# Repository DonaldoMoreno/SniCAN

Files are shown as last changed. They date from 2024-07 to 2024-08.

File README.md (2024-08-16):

# SniCAN 

## Descripción

Este proyecto consiste en el desarrollo de un sistema embebido que incluye tanto hardware como software. El objetivo del proyecto es crear un dispositivo autónomo capaz de adquirir los mensaje de un bus de CAN utilizando un microcontrolador IMXRT1060IEC, 
y una interfaz gráfica para la configuración y monitoreo.

## Características

- **Microcontrolador:** IMXRT1060IEC
- **Sensores y periféricos:** [Lista de sensores y periféricos, por ejemplo, MPU6050, OLED Display]
- **Software:**
  - **Firmware:** Implementado en C/C++ con uso de yocto zephyr.
  - **Interfaz gráfica:** Implementada en QT con Python.
- **Interfaz de usuario:** Interfaz gráfica (GUI) y línea de comandos (CLI) para configuración y monitoreo.
- **Conectividad:** CAN bus.
  
## Estructura del Repositorio

```plaintext
/SniCAN
├── /docs
├── /hardware
│   ├── /schematics
│   ├── /bom
│   ├── /fabricacion
│   ├── /simulaciones
│   ├── /documentacion
│   └── /mecanico
├── /firmware*
├── /software*
├── /simulaciones*
└── /tools*

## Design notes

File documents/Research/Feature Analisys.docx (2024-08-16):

Pins

Kicad files to make a custom Teensy 4.1, based on the official Teensy schematics, but exposing all pins for testing. All the 55 pins except D41 are brought out for testing

Pins need for:

- 1 SPI *
- 4 PWM *
- 3 CAN *
- 10 GPIO *
- 1 Power *
- LED Pin *
- Serial *
- I2C *
- Ethernet/ Future implementation
- Micro SD/ Future implementation
- LCD/ Future implementation

Displays

ILI9341 320x240 Color TFT

These displays are the best supported on Teensy 4.1, with multiple high-performance libraries for fast updates speed. ILI9341 is usually the best display to use, due to superior software support.

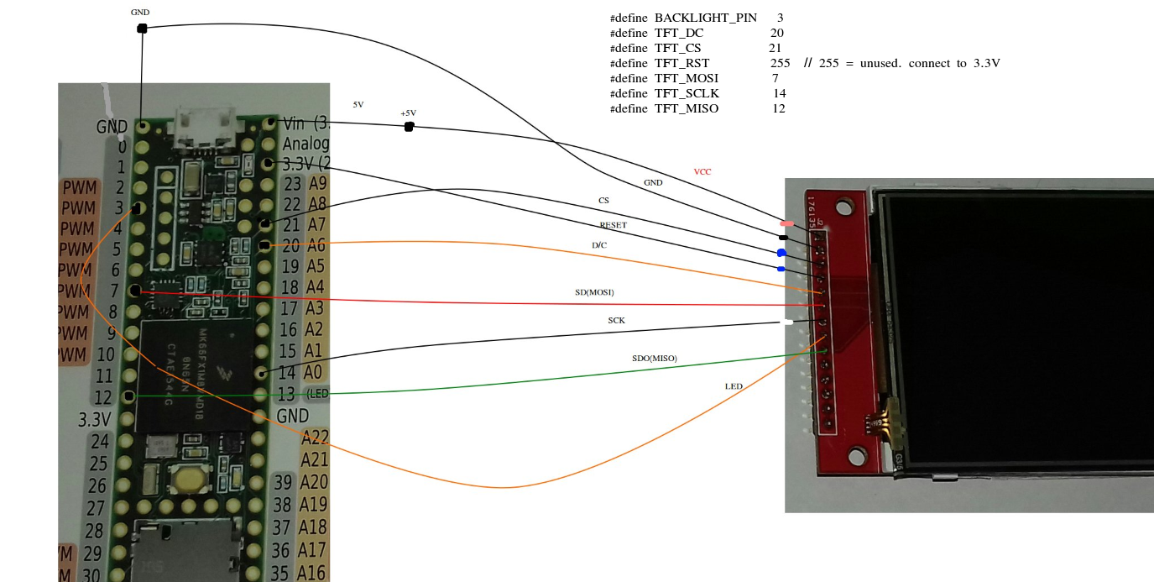
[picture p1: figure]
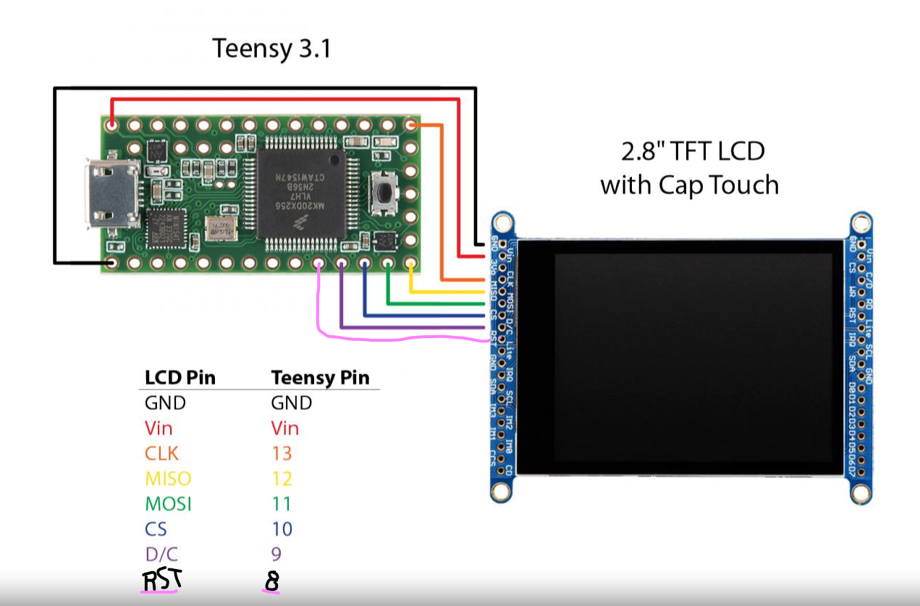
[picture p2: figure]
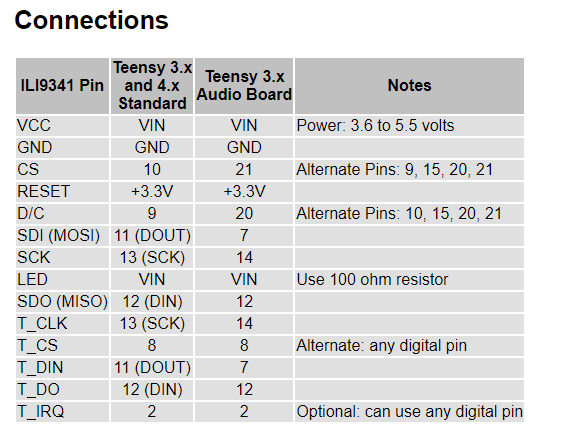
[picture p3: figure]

PWM Timers

32 timers’ control PWM pins or may be used for other timing functions. Normally these timers are accessed with analog Write or libraries, but they have many very advanced features which may be accessed by direct hardware register use.

- ~~FlexPWM1 Module0~~ ~~- Controls PWM pins 1, 44, 45.~~
- ~~FlexPWM1 Module1~~ ~~- Controls PWM pins 0, 42, 43.~~ (Usados por CAN)
- FlexPWM1 Module2 - Controls PWM pins 24, ~~46, 47~~.
- FlexPWM1 Module3 - Controls PWM pins 7, 8, 25.
- FlexPWM2 Module0 - Controls PWM pins 4, 33.
- FlexPWM2 Module1 - Controls PWM pin 5.
- FlexPWM2 Module2 - Controls PWM pins 6, 9.
- FlexPWM2 Module3 - Controls PWM pins 36, 37.
- FlexPWM3 Module0 - Controls PWM pin 53.
- FlexPWM3 Module1 - Controls PWM pins 28, 29.
- FlexPWM3 Module2 - No pins accessible.
- FlexPWM3 Module3 - Controls PWM pin 41.
- FlexPWM4 Module0 - Controls PWM pin 22.
- FlexPWM4 Module1 - Controls PWM pin 23.
- FlexPWM4 Module2 - Controls PWM pins 2, 3.

Special Timers

These extra timers allow delays, analog sample rate timing, carrier modulation, and other special timing tasks to be performed, without consuming any of the normal PWM-oriented timers.

- GPT1 - Generic 32-bit timer

CAN

3 ports for CAN bus allow connecting to automotive & industrial control systems which use CAN communication. A CAN transceiver chip must be added to complete the electrical interface between Teensy 4.1 and the CAN bus. ([CAN1 pin 22 and 23], [CAN2 pin 0 and 1], [CAN FD pin 30 and 31])

Digital Input Pins

Digital pins may be used to receive signals. Teensy 4.1 pins default to INPUT most with a "keeper" resistor. Teensy 4.1 pins accept 0 to 3.3V signals. The pins are not 5V tolerant. Do not drive any digital pin higher than 3.3V.

Power

USB Power

Normally Teensy is powered by your PC or USB hub, through a USB cable. The USB power arrives at the VUSB pin, which is connected to VIN and powers the entire board.

VIN Pin

When USB power is not used, 5V power may be applied to the VIN pin. Because VIN & VUSB are connected, power should not be applied to VIN while a USB cable is used, to prevent the possibility of power flowing back into your computer. Alternately, a pair of pads on the bottom side may be cut apart, to separate VUSB from VIN, allowing power to be safely applied while USB is in use. (TODO: VUSB-VIN pads photo, right side)

3.3V Power

Teensy 4.1 has a voltage regulator which reduces the 5V VUSB / VIN power to 3.3V for use by the main processor and most other parts. Additional circuitry may be powered from the 3.3V pin. The recommended maximum for external 3.3V usage is 250mA. Teensy 4.1 is not meant to receive power on its 3.3V pin, but this can be done with special modification.

LED Pin

Pin 13 has an orange LED connected. The LED can be very convenient to show status info. When pin 13 is used as an input, the external signal must be able to drive the LED when logic HIGH. pin Mode INPUT_PULLUP should not be used with pin 13.

Serial

8 serial ports allow you to connect serial devices, such as MIDI, GPS receivers, DMX lighting, ESP wireless modules, etc. All 8 serial ports are fully independent and can transfer data simultaneously. None are shared with USB (as is done on some Arduino boards). All 8 ports include FIFOs for better performance at high-speed baud rates. [SERIAL TX 20 and RX 21]

I2C

3 ports for I2C (signals SDA & SCL) allow connecting a wide variety of chips which use I2C communication. The Wire library is used for I2C. Each I2C chip connected to the same SDA/SCL wires needs a unique address. Multiple I2C ports allow you to easily use more than 1 chip with the same address. All I2C ports support 100, 400, and 1000 kbit/sec speeds.

SPI

3 ports for SPI (signals MOSI, MISO, SCK) allow connecting higher speed chips, SD cards, and displays which use SPI communication. The SPI library provides software support for SPI. The first SPI port features a FIFO for higher sustained speed transfers. Each SPI chip requires a chip select (CS) signal. Most libraries using SPI can use any digital pin. The SPI ports provide special hardware-controlled CS pins, which are used by specially optimized libraries for higher performance. ([SPI1 MOSI 26, SCK 27, CS 38, MISO 39],)

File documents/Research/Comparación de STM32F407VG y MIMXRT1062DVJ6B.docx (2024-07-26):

Comparación de Microcontroladores: STM32F4 vs. MIMXRT1062DVJ6B para Aplicaciones de Alto Rendimiento y Comunicación CAN

Microcontrolador | STM32F407VG | MIMXRT1062DVJ6B
Fabricante | STMicroelectronics | NXP
Arquitectura | ARM Cortex-M4 | ARM Cortex-M7
Frecuencia de reloj | 168 MHz | 600 MHz
Memoria Flash | 1 MB | Externa (FlexSPI)
SRAM | 192 KB | 1 MB en chip
Interfaces de comunicación | - 3x CAN - 4x USART - 3x SPI - 3x I2C - 2x USB OTG (FS y HS) | - 1x CAN FD - 1x CAN 2.0 - 8x UART - 4x SPI - 4x I2C - 2x USB OTG (FS y HS)
Aceleradores DSP y FPU | Si | Si
DMA | 12 canales | 32 canales
GPIO | 140 pines | 150 pines
ADC | 3x ADC de 12 bits | 2x ADC de 12 bits
DAC | 2x DAC de 12 bits | 1x DAC de 12 bits
Temperatura de operación | -40°C a 85°C | -40°C a 105°C
Paquetes | LQFP, BGA | LQFP, BGA
Disponibilidad | Buena en el mercado. | Buena en el mercado.
Precio (+100 piezas) | $11.36 | $12.73
Certificaciones | Varias, incluidas aplicaciones automotrices. | Varias, incluidas aplicaciones automotrices.
Seguridad | Características básicas de seguridad. | Características avanzadas de seguridad.

Comparación

1. Arquitectura y Rendimiento:

- STM32F4: Basado en ARM Cortex-M4, hasta 168 MHz.

- MIMXRT1062DVJ6B: Basado en ARM Cortex-M7, hasta 600 MHz. El Cortex-M7 ofrece un mayor rendimiento en comparación con el Cortex-M4, especialmente para aplicaciones que requieren procesamiento intensivo.

2. Memoria:

- STM32F4: Hasta 1 MB de Flash interna y 192 KB de SRAM.

- MIMXRT1062DVJ6B: No tiene Flash interna, usa memoria externa (FlexSPI), pero tiene 1 MB de SRAM en chip.

3. Interfaces de Comunicación:

- STM32F4: 3x CAN, más interfaces USART, SPI, I2C, y USB.

- MIMXRT1062DVJ6B: 1x CAN FD, 1x CAN 2.0, más interfaces UART, SPI, I2C, y USB. La inclusión de CAN FD es una ventaja para aplicaciones que requieren velocidades de datos más altas en la comunicación CAN.

4. DMA:

- STM32F4: 12 canales.

- MIMXRT1062DVJ6B: 32 canales, lo que permite una mayor flexibilidad y capacidad para manejar múltiples periféricos simultáneamente.

5. Temperatura de Operación:

- Ambos microcontroladores operan en un rango industrial, pero el MIMXRT1062DVJ6B soporta hasta 105°C, lo cual es una ventaja para aplicaciones en entornos más exigentes.

6. GPIO:

- STM32F4: Hasta 140 pines.

- MIMXRT1062DVJ6B: Hasta 150 pines, proporcionando más opciones de conexión.

Conclusión Características

- STM32F4 es una excelente opción para aplicaciones que requieren una combinación equilibrada de rendimiento y funcionalidades con una arquitectura Cortex-M4 probada.

- MIMXRT1062DVJ6B es más adecuado para aplicaciones que requieren un alto rendimiento y capacidad de procesamiento, gracias a su núcleo Cortex-M7 y su alta frecuencia de reloj. Además, la inclusión de CAN FD lo hace ideal para aplicaciones automotrices avanzadas y otras aplicaciones que requieren comunicación de alta velocidad en el bus CAN.

COMPARATIVA DE COSTOS DE DESARROLLO PARA EL STM32F4 Y EL MIMXRT1062DVJ6B

Una comparación de costos considerando una implementación básica para CAN, incluyendo el costo del microcontrolador y los componentes esenciales para la comunicación CAN.

### STM32F407VG

7. Costo del Microcontrolador:
  - $9.27 (1000) a $14.64 USD por unidad.
8. Transceptor CAN:
  - MCP2551 o similar: Aproximadamente $0.50 a $1.50 USD por unidad.
9. Componentes Pasivos (resistencias, condensadores, etc.):
  - Aproximadamente $0.50 a $1.00 USD por unidad.
10. Conectores y Placa de Circuito Impreso (PCB):
  - Aproximadamente $2 a $5 USD por unidad.

### Costo Total Estimado para STM32F4:

- Total: $13 a $22 USD por unidad.

### MIMXRT1062DVJ6B

1. Costo del Microcontrolador:
  - $10.01 (1000) a $15.90 USD por unidad.
2. Transceptor CAN FD:
  - MCP2562FD o similar: Aproximadamente $1 a $2 USD por unidad.
3. Componentes Pasivos (resistencias, condensadores, etc.):
  - Aproximadamente $0.50 a $1.00 USD por unidad.
4. Conectores y Placa de Circuito Impreso (PCB):
  - Aproximadamente $2 a $5 USD por unidad.

### Costo Total Estimado para MIMXRT1062DVJ6B:

- Total: $10.50 a $18 USD por unidad.

### Comparación de Costos

Componente | STM32F4 (STM32F407VG) | MIMXRT1062DVJ6B
Microcontrolador | $9.27 - $14.64 USD | $10.01 - $15.90 USD
Transceptor CAN | $0.50 - $1.50 USD | $1 - $2 USD
Componentes Pasivos | $0.50 - $1 USD | $0.50 - $1 USD
Conectores y PCB | $2 - $5 USD | $2 - $5 USD
Costo Total Estimado | $12.27 - $22.14 USD | $13.51 - $23.90 USD

Fuente

- Digikey (https://www.digikey.com/en/products/detail/nxp-usa-inc/MIMXRT1062DVJ6B/13574426?gad_source=1)
- Mouser (https://www.mouser.com/c/semiconductors/embedded-processors-controllers/microcontrollers-mcu/arm-microcontrollers-mcu/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)

Conclusión costos

El MIMXRT1062DVJ6B ofrece un costo ligeramente superior para una implementación básica de CAN en comparación con el STM32F4. Sin embargo, el MIMXRT1062DVJ6B proporciona un rendimiento superior y soporte para CAN FD, lo que puede ser beneficioso por los requisitos específicos de aplicación.

COMPARATIVA DE ECOSISTEMAS DE DESARROLLO PARA EL STM32F4 Y EL MIMXRT1062DVJ6B

### Ecosistema de Desarrollo STM32F407VG

1. Herramientas de Desarrollo
  - STM32CubeIDE: IDE basado en Eclipse, proporciona un entorno de desarrollo integrado con soporte completo para depuración y compilación.
  - STM32CubeMX: Herramienta para la configuración de microcontroladores STM32 y generación de código de inicialización.
  - KEIL MDK: IDE de desarrollo profesional con compilador ARM y herramientas avanzadas de depuración.
  - IAR Embedded Workbench: IDE con compilador y depurador optimizado para aplicaciones embebidas.
2. Bibliotecas y Middleware
  - STM32Cube HAL (Hardware Abstraction Layer): Biblioteca de abstracción de hardware que facilita el uso de periféricos.
  - STM32 Standard Peripheral Libraries: Librerías de bajo nivel para acceso a periféricos.
  - CMSIS (Cortex Microcontroller Software Interface Standard): Conjunto de APIs estándar para programación en microcontroladores Cortex.
3. Kits de Desarrollo y Placas
  - STM32 Nucleo Boards: Placas de desarrollo versátiles y económicas con soporte para Arduino shields.
  - Discovery Kits: Placas con funcionalidades avanzadas, incluyendo pantallas, sensores y conectividad.
  - Evaluation Boards: Placas completas con todos los periféricos y interfaces expuestas para pruebas exhaustivas.
4. Documentación y Recursos
  - Manuales de Referencia y Datasheets: Documentos detallados sobre el funcionamiento interno y características del microcontrolador.
  - Guías de Usuario y Aplicación: Documentos que explican cómo utilizar y configurar los diferentes periféricos y características.
  - Ejemplos de Código: Proyectos de ejemplo para una variedad de aplicaciones y periféricos.
5. Soporte de Comunidad
  - ST Community: Foro oficial de STMicroelectronics con soporte de expertos y usuarios.
  - STM32 Forums: Foros independientes donde los desarrolladores comparten experiencias y soluciones.
  - GitHub: Repositorios con proyectos de código abierto y ejemplos.
6. Capacitación y Cursos
  - MOOCs y Webinars: Cursos online y webinars ofrecidos por ST y otros proveedores de formación.
  - Documentación Educativa: Recursos educativos y libros sobre programación y desarrollo con STM32.

### Ecosistema de Desarrollo MIMXRT1062DVJ6B

1. Herramientas de Desarrollo
  - MCUXpresso IDE: Entorno de desarrollo integrado proporcionado por NXP, basado en Eclipse, con soporte completo para depuración y compilación.
  - MCUXpresso Config Tools: Herramienta para la configuración de microcontroladores y generación de código de inicialización.
  - IAR Embedded Workbench: IDE con compilador y depurador optimizado para aplicaciones embebidas.
  - KEIL MDK: IDE de desarrollo profesional con compilador ARM y herramientas avanzadas de depuración.
2. Bibliotecas y Middleware
  - MCUXpresso SDK: Conjunto de software development kits que incluyen drivers, middleware y ejemplos de aplicaciones.
  - FreeRTOS: Soporte integrado para el sistema operativo en tiempo real FreeRTOS.
  - USB y TCP/IP Stacks: Pilas de comunicación USB y TCP/IP para desarrollo de aplicaciones de conectividad.
3. Kits de Desarrollo y Placas
  - MIMXRT1060-EVK: Kit de evaluación completo para el MIMXRT1062, con todos los periféricos y interfaces necesarias para pruebas exhaustivas.
  - Development Boards de Terceros: Placas de desarrollo ofrecidas por otros fabricantes compatibles con el microcontrolador.
4. Documentación y Recursos
  - Manuales de Referencia y Datasheets: Documentos detallados sobre el funcionamiento interno y características del microcontrolador.
  - Guías de Usuario y Aplicación: Documentos que explican cómo utilizar y configurar los diferentes periféricos y características.
  - Ejemplos de Código: Proyectos de ejemplo para una variedad de aplicaciones y periféricos.
5. Soporte de Comunidad
  - NXP Community: Foro oficial de NXP con soporte de expertos y usuarios.
  - GitHub: Repositorios con proyectos de código abierto y ejemplos.
  - Stack Overflow: Comunidad activa con preguntas y respuestas relacionadas con el desarrollo en microcontroladores NXP.
6. Capacitación y Cursos
  - Webinars y Seminarios: Eventos educativos y seminarios en línea ofrecidos por NXP.
  - Documentación Educativa: Recursos educativos y libros sobre programación y desarrollo con microcontroladores NXP.

### Comparación de Ecosistemas

Aspecto | STM32F407VG | MIMXRT1062DVJ6B
IDE Principal | STM32CubeIDE, KEIL, IAR | MCUXpresso IDE, KEIL, IAR
Herramientas de Configuración | STM32CubeMX | MCUXpresso Config Tools
SDK y Middleware | STM32Cube HAL, CMSIS | MCUXpresso SDK, FreeRTOS, USB/TCP/IP
Placas de Desarrollo | Nucleo Boards, Discovery Kits | MIMXRT1060-EVK, placas de terceros
Documentación | Completa y detallada | Completa y detallada
Comunidad | Amplia, activa, múltiples foros | Amplia, activa, NXP Community, GitHub
Capacitación | MOOCs, webinars, documentación educativa | Webinars, seminarios, documentación educativa
Ejemplos de Código | Abundantes y variados | Abundantes y variados

### Conclusión comparación de ecosistemas de desarrollo

Ambos ecosistemas de desarrollo son robustos y completos, ofreciendo una amplia gama de herramientas, bibliotecas, documentación y soporte comunitario. La elección entre el ecosistema STM32F4 y el MIMXRT1062DVJ6B dependerá de las preferencias personales del desarrollador, la experiencia previa y las necesidades específicas del proyecto. El ecosistema STM32 es muy conocido por su facilidad de uso y la abundancia de recursos educativos, mientras que el ecosistema NXP ofrece herramientas poderosas y soporte para características avanzadas como CAN FD y alto rendimiento de procesamiento.

COMPARATIVA DE CERTIFICACIONES DE DESARROLLO PARA EL STM32F4 Y EL MIMXRT1062DVJ6B

### Certificaciones y Conformidades del MIMXRT1062DVJ6B

1. Certificación Automotriz
  - AEC-Q100: El MIMXRT1062DVJ6B no está calificado bajo AEC-Q100, que es un estándar para la fiabilidad de componentes electrónicos en aplicaciones automotrices. Sin embargo, NXP tiene otros microcontroladores en su línea que sí cumplen con esta certificación.
2. Certificación de Seguridad Funcional
  - IEC 61508: NXP proporciona productos que pueden ser utilizados en aplicaciones que requieren el cumplimiento con IEC 61508 para la seguridad funcional. Aunque el MIMXRT1062DVJ6B no está específicamente certificado, puede ser parte de un sistema que cumple con esta norma.
  - ISO 26262: Similar a IEC 61508, este microcontrolador puede ser utilizado en aplicaciones que necesitan cumplir con ISO 26262 para la seguridad funcional automotriz, pero no está específicamente certificado para ello.
3. Certificación Industrial
  - IEC 60730: NXP ofrece soporte para IEC 60730, que es una norma relevante para aplicaciones seguras en electrodomésticos. El MIMXRT1062DVJ6B puede ser utilizado en sistemas que necesitan cumplir con esta norma.
4. Certificación Médica
  - IEC 62304: Aunque no está específicamente certificado, el MIMXRT1062DVJ6B puede ser parte de dispositivos médicos que necesitan cumplir con la norma IEC 62304 para el software de dispositivos médicos.

### Certificaciones y Conformidades del STM32F407VG

1. Certificación Automotriz
  - AEC-Q100: Algunos modelos de la serie STM32F4, incluidos ciertos modelos específicos, están calificados bajo AEC-Q100. Sin embargo, el STM32F407VG en particular no está certificado AEC-Q100. STMicroelectronics ofrece otros modelos dentro de la serie STM32 que sí cumplen con esta certificación.
2. Certificación de Seguridad Funcional
  - IEC 61508: La serie STM32F4 puede ser utilizada en aplicaciones que requieren cumplimiento con IEC 61508 para la seguridad funcional. Sin embargo, el STM32F407VG no está específicamente certificado para esta norma, aunque puede ser parte de un sistema que cumple con IEC 61508.
  - ISO 26262: Similar a IEC 61508, algunos microcontroladores de la serie STM32 están diseñados para ayudar a cumplir con la norma ISO 26262, pero el STM32F407VG en particular no tiene esta certificación explícita.
3. Certificación Industrial
  - IEC 60730: La serie STM32F4, incluido el STM32F407VG, puede ser utilizada en aplicaciones que necesitan cumplir con la norma IEC 60730 para la seguridad de electrodomésticos y aplicaciones industriales.
4. Certificación Médica
  - IEC 62304: Los microcontroladores de la serie STM32, incluidos ciertos modelos de la serie F4, pueden ser utilizados en dispositivos médicos que necesitan cumplir con IEC 62304 para el software de dispositivos médicos. El STM32F407VG puede ser parte de un sistema que cumple con esta norma, pero no está específicamente certificado.

### Comparación de Certificaciones

Certificación | MIMXRT1062DVJ6B | STM32F407VG
Automotriz (AEC-Q100) | No | No (otros modelos STM32F4 sí)
Seguridad Funcional (IEC 61508) | No específicamente, pero puede utilizarse en sistemas que cumplen | No específicamente, pero puede utilizarse en sistemas que cumplen
Seguridad Funcional (ISO 26262) | No específicamente, pero puede utilizarse en sistemas que cumplen | No específicamente, pero puede utilizarse en sistemas que cumplen
Industrial (IEC 60730) | Puede ser utilizado en sistemas que cumplen | Puede ser utilizado en sistemas que cumplen
Médica (IEC 62304) | Puede ser utilizado en sistemas que cumplen | Puede ser utilizado en sistemas que cumplen

### Conclusión comparativa de certificaciones

Ninguno de los microcontroladores (MIMXRT1062DVJ6B y STM32F407VG) está específicamente certificado para todas las normas mencionadas, pero ambos pueden ser utilizados en sistemas que cumplen con estas certificaciones, dependiendo de la implementación y las evaluaciones adicionales realizadas por los desarrolladores. La elección entre estos microcontroladores dependerá en gran medida de otros factores como el rendimiento, los periféricos y el soporte del ecosistema, además de las certificaciones específicas requeridas para la aplicación final.

COMPARATIVA DE SEGURIDAD DE DESARROLLO PARA EL STM32F4 Y EL MIMXRT1062DVJ6B

### Características de Seguridad del MIMXRT1062DVJ6B

1. Arranque Seguro (Secure Boot)
  - Características: Soporte para arranque seguro que asegura que solo código firmado y autorizado puede ejecutarse en el dispositivo.
  - Beneficio: Protege contra la ejecución de firmware no autorizado o malicioso.
2. Almacenamiento Seguro
  - Flash Seguro: Soporte para particiones seguras en memoria flash.
  - Protección de Lectura y Escritura: Configuración para proteger ciertas áreas de memoria de ser leídas o escritas por código no autorizado.
3. Criptografía
  - Aceleradores Criptográficos: Hardware integrado para acelerar operaciones criptográficas como AES, RSA, SHA, y ECC.
  - Generador de Números Aleatorios (TRNG): Hardware que proporciona números aleatorios de alta calidad para operaciones criptográficas.
4. Gestión de Claves
  - Almacenamiento Seguro de Claves: Módulos específicos para almacenar claves criptográficas de manera segura.
  - Generación y Gestión de Claves: Soporte para la generación, almacenamiento y gestión segura de claves.
5. Detección de Intrusiones
  - Monitores de Voltaje y Temperatura: Detecta condiciones fuera de los parámetros normales que podrían indicar un intento de intrusión.
  - Protección contra Manipulaciones: Mecanismos para detectar y responder a intentos de manipulación física del dispositivo.
6. Protección de Memoria
  - Unidad de Protección de Memoria (MPU): Configura y protege regiones de memoria contra accesos no autorizados.
  - Códigos de Integridad: Verificación de la integridad del código y datos almacenados en memoria.

### Características de Seguridad del STM32F407VG

1. Arranque Seguro (Secure Boot)
  - Características: No tiene soporte nativo para arranque seguro. Sin embargo, puede ser implementado mediante software adicional y configuraciones específicas.
2. Almacenamiento Seguro
  - Protección de Lectura y Escritura: Ofrece opciones para proteger la memoria flash contra lecturas y escrituras no autorizadas mediante niveles de protección (RDP - Read Protection).
3. Criptografía
  - Aceleradores Criptográficos: Incluye aceleradores de hardware para operaciones AES y hash (SHA-1, SHA-256).
  - Generador de Números Aleatorios (RNG): Hardware para generar números aleatorios, aunque es un RNG no certificado como TRNG.
4. Gestión de Claves
  - Almacenamiento Seguro de Claves: No tiene módulos específicos para el almacenamiento seguro de claves, pero las claves pueden ser protegidas mediante software.
  - Generación y Gestión de Claves: Las claves deben ser gestionadas y almacenadas a través de software y configuraciones adicionales.
5. Detección de Intrusiones
  - Monitores de Voltaje y Temperatura: No tiene monitores específicos para detección de intrusiones.
  - Protección contra Manipulaciones: Carece de mecanismos avanzados para detectar manipulación física.
6. Protección de Memoria
  - Unidad de Protección de Memoria (MPU): Soporta configuración de MPU para proteger regiones de memoria contra accesos no autorizados.
  - Códigos de Integridad: Puede implementar verificaciones de integridad de código mediante software.

### Comparación de Seguridad

Característica | MIMXRT1062DVJ6B | STM32F407VG
Arranque Seguro (Secure Boot) | Sí | No nativo, puede ser implementado vía software
Almacenamiento Seguro | Flash seguro, protección de lectura/escritura | Protección de lectura/escritura mediante RDP
Criptografía | Aceleradores para AES, RSA, SHA, ECC; TRNG | Aceleradores para AES, SHA; RNG no certificado
Gestión de Claves | Almacenamiento y gestión segura de claves | No tiene módulos específicos, depende de software
Detección de Intrusiones | Monitores de voltaje y temperatura, protección contra manipulación | No tiene detección avanzada de intrusiones
Protección de Memoria | MPU, códigos de integridad | MPU, puede implementar verificaciones de integridad vía software

### Conclusión seguridad

El MIMXRT1062DVJ6B de NXP ofrece un conjunto más robusto de características de seguridad en comparación con el STM32F407VG de STMicroelectronics. Incluye soporte nativo para arranque seguro, aceleradores criptográficos avanzados, almacenamiento seguro de claves y detección de intrusiones, lo que lo hace más adecuado para aplicaciones que requieren altos niveles de seguridad.

Por otro lado, el STM32F407VG ofrece algunas características básicas de seguridad como protección de memoria y aceleradores criptográficos, pero carece de soporte nativo para arranque seguro y almacenamiento seguro de claves, lo que puede requerir soluciones adicionales basadas en software para cumplir con requisitos de seguridad más estrictos.

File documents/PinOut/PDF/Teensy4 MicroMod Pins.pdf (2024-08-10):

Pin | MM Pin | Name | GPIO | Serial | I2C | SPI | PWM | CAN | Audio | XBAR | FlexIO | Analog | SD/CSI/LCD
0 | 19 | AD_B0_03 | 1.3 | Serial1(6) RX | SPI1(3) CS0 | PWM1_X1 2_RX | IO-17
1 | 17 | AD_B0_02 | 1.2 | Serial1(6) TX | SPI1(3) MISO | PWM1_X0 2_TX | IO-16
2 | 47 | EMC_04 | 4.4 | PWM4_A2 | 2:TX_DATAIO-06 | 1:4
3 | 32 | EMC_05 | 4.5 | PWM4_B2 | 2:TX_SYNCIO-07 | 1:5
4 | 10 | EMC_06 | 4.6 | PWM2_A0 | 2:TX_BCLKIO-08 | 1:6
5 | 18 | EMC_08 | 4.8 | PWM2_A1 | 2:RX_DATAIO-17 | 1:8
6 | 71 | B0_10 | 2.10 | PWM2_A2, QT4_1 | 1:TX3_RX1 | 2:10 | LCD_DATA6
7 | 56 | B1_01 | 2.17 | Serial4(4) RX | PWM1_B3 | 1:TX_DATAIO-15 | 2:17, 3:17
8 | 54 | B1_00 | 2.16 | Serial4(4) TX | PWM1_A3 | 1:RX_DATAIO-14 | 2:16, 3:16
9 | 69 | B0_11 | 2.11 | PWM2_B2,QT4_2 | 1:TX2_RX2 | 2:11 | LCD_DATA7
10 | 55 | B0_00 | 2.0 | SPI(4) CS0 | QT1_0 | MQS_RIGHT | 2:0 | LCD_CLK
11 | 59 | B0_02 | 2.2 | | | SPI(4) MOSI | QT1_2 | 1_TX | | | 2:2 | | LCD_HSYNC
12 | 61 | B0_01 | 2.1 | SPI(4) MISO | QT1_1 | MQS_LEFT | 2:1 | LCD_ENABLE
13 | 57 | B0_03 | 2.3 | | | SPI(4) SCK | QT2_0 | 1_RX | | | 2:3 | | LCD_VSYNC
14/A0 | 34 | AD_B1_02 | 1.18 | Serial3(2) TX | QT3_2 | SPDIF_OUT | 3:2 | A1:7, A2:7
15/A1 | 38 | AD_B1_03 | 1.19 | Serial3(2) RX | | | QT3_3 | | SPDIF_IN | | 3:3 | A1:8, A2:8
16/A2 | 20 | AD_B1_07 | 1.23 | Serial2(3) RX Wire2(3) SCL | SPDIF_EXTCLK | 3:7 | A1:12, A2:12 | USDHC2_DATA3
17/A3 | 22 | AD_B1_06 | 1.22 | Serial2(3) TX Wire2(3) SDA | SPDIF_LOCK | 3:6 | A1:11, A2:11 | USDHC2_DATA2
18/A4 | 12 | AD_B1_01 | 1.17 | Serial3(2) RTS Wire(1) SDA | QT3_1 | 3:1 | A1:6, A2:6
19/A5 | 14 | AD_B1_00 | 1.16 | Serial3(2) CTS Wire(1) SCL | QT3_0 | 3:0 | A1:5, A2:5
20/A6 | 52 | AD_B1_10 | 1.26 | Serial5(8) TX | 1:RX_SYNC | 3:10 | A1:15, A2:15
21/A7 | 50 | AD_B1_11 | 1.27 | Serial5(8) RX | 1:RX_BCLK | 3:11 | A1:0, A2:0
22/A8 | 49 | AD_B1_08 | 1.24 | PWM4_A0 1_TX | 3:8 | A1:13, A2:13 | USDHC2_CMD
23/A9 | 58 | AD_B1_09 | 1.25 | PWM4_A1 1_RX | 1:MCLK | 3:9 | A1:14, A2:14 | USDHC2_CLK
24/A10 | 53 | AD_B0_12 | 1.12 | Serial6(1) TX Wire1(4) SCL | PWM1_X2 | A1:1
25/A11 | 51 | AD_B0_13 | 1.13 | Serial6(1) RX Wire1(4) SDA | PWM1_X3 GPT1_CLK | A1:2
26/A12 | 67 | AD_B1_14 | 1.30 | SPI1(3) MOSI | 1:TX_BCLK | 3:14 | A2:3
27/A13 | 8 | AD_B1_15 | 1.31 | SPI1(3) SCK | 1:TX_SYNC | 3:15 | A2:4
28 | 4 | EMC_32 | 3.18 | Serial7(7) RX | | | PWM3_B1
29 | 16 | EMC_31 | 4.31 | Serial7(7) TX | | SPI2(1) CS1 | PWM3_A1
30 | 41 | EMC_37 | 3.23 | GPT1_3 | 3_RX | 3:MCLK IO-23
31 | 43 | EMC_36 | 3.22 | GPT1_2 | 3_TX | 3:TX_DATAIO-22
32 | 65 | B0_12 | 2.12 | 1:TX1_RX3IO-10 | 2:12 | LCD_DATA8
33 | 63 | EMC_07 | 4.7 | PWM2_B0 | 2:MCLK IO-09 | 1:7
SD Pins - Cable connector(T4 34-39)
34 | 66 | SD_B0_03 | 3.15 | Serial5(8) RTS | | SPI2(1) MISO | PWM1_B1 | | | IO-07 | | | DATA1
35 | 64 | SD_B0_02 | 3.14 | Serial5(8) CTS | | SPI2(1) MOSI | PWM1_A1 | | | IO-06 | | | DATA0
36 | 60 | SD_B0_01 | 3.13 | | Wire2(3) SDA | SPI2(1) CS0 | PWM1_B0 | | | IO-05 | | | CLK
37 | 62 | SD_B0_00 | 3.12 | | Wire2(3) SCL | SPI2(1) SCK | PWM1_A0 | | | IO-04 | | | CMD
38 | 68 | SD_B0_04 | 3.16 | Serial5(8) TX | FLEXSPI B_SSO_B PWM1_A2 | IO-08 | DATA2
39 | 70 | SD_B0_05 | 3.17 | Serial5(8) RX | | FLEXSPI B_DQS | PWM1_B2 | | | IO-09 | | | DATA3
Micromod new pins
40 | 40 | B0_04 | 2:04 | | Wire3(2) SCL | | QT2_1 | | | | 2:4 | | LCD_DATA0
41 | 42 | B0_05 | 2:05 | | Wire3(2) SDA | | QT2_2 | | | | 2:5 | | LCD_DATA1
42 | 44 | B0_06 | 2:06 | | | | QT3_0 | | | | 2:6 | | LCD_DATA2
43 | 46 | B0_07 | 2:07 | | | | QT3_1 | | | | 2:7 | | LCD_DATA3
44 | 48 | B0_08 | 2:08 | | | | QT3_2 | | | | 2:8 | | LCD_DATA4
45 | 73 | B0_09 | 2:09 | | | | QT4_0 | | | | 2:9 | | LCD_DATA5
USB Pins
HUSB D+ 35
HUSB D- 37
USB D+ | 3
USB D- | 5

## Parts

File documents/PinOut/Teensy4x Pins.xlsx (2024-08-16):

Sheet: T4
Pin | Name | GPIO | Serial | I2C | SPI | PWM | CAN | Audio | XBAR | FlexIO | Analog | SD
0 | AD_B0_03 | 1.3 | Serial1(6) RX |  | SPI1(3) CS0 | PWM1_X1 | 2_RX |  | IO-17
1 | AD_B0_02 | 1.2 | Serial1(6) TX |  | SPI1(3) MISO | PWM1_X0 | 2_TX |  | IO-16
2 | EMC_04 | 4.4 |  |  |  | PWM4_A2 |  | 2:TX_DATA | IO-06 | 1:4
3 | EMC_05 | 4.5 |  |  |  | PWM4_B2 |  | 2:TX_SYNC | IO-07 | 1:5
4 | EMC_06 | 4.6 |  |  |  | PWM2_A0 |  | 2:TX_BCLK | IO-08 | 1:6
5 | EMC_08 | 4.8 |  |  |  | PWM2_A1 |  | 2:RX_DATA | IO-17 | 1:8
6 | B0_10 | 2.10 |  |  |  | PWM2_A2, QT4_1 |  | 1:TX3_RX1 |  | 2:10
7 | B1_01 | 2.17 | Serial2(4) RX |  |  | PWM1_B3 |  | 1:TX_DATA | IO-15 | 2:17, 3:17
8 | B1_00 | 2.16 | Serial2(4) TX |  |  | PWM1_A3 |  | 1:RX_DATA | IO-14 | 2:16, 3:16
9 | B0_11 | 2.11 |  |  |  | PWM2_B2, QT4_2 |  | 1:TX2_RX2 |  | 2:11
10 | B0_00 | 2.0 |  |  | SPI(4) CS0 | QT1_0 |  | MQS_RIGHT |  | 2:0
11 | B0_02 | 2.2 |  |  | SPI(4) MOSI | QT1_2 | 1_TX |  |  | 2:2
12 | B0_01 | 2.1 |  |  | SPI(4) MISO | QT1_1 |  | MQS_LEFT |  | 2:1
13 | B0_03 | 2.3 |  |  | SPI(4) SCK | QT2_0 | 1_RX |  |  | 2:3
14/A0 | AD_B1_02 | 1.18 | Serial3(2) TX |  |  | QT3_2 |  | SPDIF_OUT |  | 3:2 | A1:7, A2:7
15/A1 | AD_B1_03 | 1.19 | Serial3(2) RX |  |  | QT3_3 |  | SPDIF_IN |  | 3:3 | A1:8, A2:8
16/A2 | AD_B1_07 | 1.23 | Serial4(3) RX | Wire1(3) SCL |  |  |  | SPDIF_EXTCLK |  | 3:7 | A1:12, A2:12
17/A3 | AD_B1_06 | 1.22 | Serial4(3) TX | Wire1(3) SDA |  |  |  | SPDIF_LOCK |  | 3:6 | A1:11, A2:11
18/A4 | AD_B1_01 | 1.17 | Serial3(2) RTS | Wire(1) SDA |  | QT3_1 |  |  |  | 3:1 | A1:6, A2:6
19/A5 | AD_B1_00 | 1.16 | Serial3(2) CTS | Wire(1) SCL |  | QT3_0 |  |  |  | 3:0 | A1:5, A2:5
20/A6 | AD_B1_10 | 1.26 | Serial5(8) TX |  |  |  |  | 1:RX_SYNC |  | 3:10 | A1:15, A2:15
21/A7 | AD_B1_11 | 1.27 | Serial5(8) RX |  |  |  |  | 1:RX_BCLK |  | 3:11 | A1:0, A2:0
22/A8 | AD_B1_08 | 1.24 |  |  |  | PWM4_A0 | 1_TX |  |  | 3:8 | A1:13, A2:13
23/A9 | AD_B1_09 | 1.25 |  |  |  | PWM4_A1 | 1_RX | 1:MCLK |  | 3:9 | A1:14, A2:14
--- | ---- | ---- | ------ | --- | --- | --- | --- | ---- | ---- | ----- | ------
24/A10 | AD_B0_12 | 1.12 | Serial6(1) TX | Wire2(4) SCL |  | PWM1_X2 |  |  |  |  | A1:1
25/A11 | AD_B0_13 | 1.13 | Serial6(1) RX | Wire2(4) SDA |  | PWM1_X3 | GPT1_CLK |  |  |  | A1:2
26/A12 | AD_B1_14 | 1.30 |  |  | SPI1(3) MOSI |  |  | 1:TX_BCLK |  | 3:14 | A2:3
27/A13 | AD_B1_15 | 1.31 |  |  | SPI1(3) SCK |  |  | 1:TX_SYNC |  | 3:15 | A2:4
28 | EMC_32 | 3.18 | Serial7(7) RX |  |  | PWM3_B1
29 | EMC_31 | 4.31 | Serial7(7) TX |  | SPI2(1) CS1 | PWM3_A1
30 | EMC_37 | 3.23 |  |  |  | GPT1_3 | 3_RX | 3:MCLK | IO-23
31 | EMC_36 | 3.22 |  |  |  | GPT1_2 | 3_TX | 3:TX_DATA | IO-22
32 | B0_12 | 2.12 |  |  |  |  |  | 1:TX1_RX3 | IO-10 | 2:12
33 | EMC_07 | 4.7 |  |  |  | PWM2_B0 |  | 2:MCLK | IO-09 | 1:7
34 | SD_B0_03 | 3.15 | Serial5(8) RTS |  | SPI2(1) MISO | PWM1_B1 |  |  | IO-07 |  |  | DATA1
35 | SD_B0_02 | 3.14 | Serial5(8) CTS |  | SPI2(1) MOSI | PWM1_A1 |  |  | IO-06 |  |  | DATA0
36 | SD_B0_01 | 3.13 |  | Wire1(3) SDA | SPI2(1) CS0 | PWM1_B0 |  |  | IO-05 |  |  | CLK
37 | SD_B0_00 | 3.12 |  | Wire1(3) SCL | SPI2(1) SCK | PWM1_A0 |  |  | IO-04 |  |  | CMD
38 | SD_B0_05 | 3.17 | Serial5(8) RX |  | SPI2(1) B_DQS | PWM1_B2 |  |  | IO-09 |  |  | DATA3
39 | SD_B0_04 | 3.16 | Serial5(8) TX |  | SPI2(1) B_SSO_B | PWM1_A2 |  |  | IO-08 |  |  | DATA2

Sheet: T4 - GPIO
Pin | Name | GPIO | Serial | I2C | SPI | PWM | CAN | Audio | XBAR | FlexIO | Analog | SD
1 | AD_B0_02 | 1.02 | Serial1(6) TX |  | SPI1(3) MISO | PWM1_X0 | 2_TX |  | IO-16
0 | AD_B0_03 | 1.03 | Serial1(6) RX |  | SPI1(3) CS0 | PWM1_X1 | 2_RX |  | IO-17
24/A10 | AD_B0_12 | 1.12 | Serial6(1) TX | Wire2(4) SCL |  | PWM1_X2 |  |  |  |  | A1:1
25/A11 | AD_B0_13 | 1.13 | Serial6(1) RX | Wire2(4) SDA |  | PWM1_X3 | GPT1_CLK |  |  |  | A1:2
19/A5 | AD_B1_00 | 1.16 | Serial3(2) CTS | Wire(1) SCL |  | QT3_0 |  |  |  | 3:0 | A1:5, A2:5
18/A4 | AD_B1_01 | 1.17 | Serial3(2) RTS | Wire(1) SDA |  | QT3_1 |  |  |  | 3:1 | A1:6, A2:6
14/A0 | AD_B1_02 | 1.18 | Serial3(2) TX |  |  | QT3_2 |  | SPDIF_OUT |  | 3:2 | A1:7, A2:7
15/A1 | AD_B1_03 | 1.19 | Serial3(2) RX |  |  | QT3_3 |  | SPDIF_IN |  | 3:3 | A1:8, A2:8
17/A3 | AD_B1_06 | 1.22 | Serial4(3) TX | Wire1(3) SDA |  |  |  | SPDIF_LOCK |  | 3:6 | A1:11, A2:11
16/A2 | AD_B1_07 | 1.23 | Serial4(3) RX | Wire1(3) SCL |  |  |  | SPDIF_EXTCLK |  | 3:7 | A1:12, A2:12
22/A8 | AD_B1_08 | 1.24 |  |  |  | PWM4_A0 | 1_TX |  |  | 3:8 | A1:13, A2:13
23/A9 | AD_B1_09 | 1.25 |  |  |  | PWM4_A1 | 1_RX | 1:MCLK |  | 3:9 | A1:14, A2:14
20/A6 | AD_B1_10 | 1.26 | Serial5(8) TX |  |  |  |  | 1:RX_SYNC |  | 3:10 | A1:15, A2:15
21/A7 | AD_B1_11 | 1.27 | Serial5(8) RX |  |  |  |  | 1:RX_BCLK |  | 3:11 | A1:0, A2:0
26/A12 | AD_B1_14 | 1.30 |  |  | SPI1(3) MOSI |  |  | 1:TX_BCLK |  | 3:14 | A2:3
27/A13 | AD_B1_15 | 1.31 |  |  | SPI1(3) SCK |  |  | 1:TX_SYNC |  | 3:15 | A2:4
10 | B0_00 | 2.00 |  |  | SPI(4) CS0 | QT1_0 |  | MQS_RIGHT |  | 2:0
12 | B0_01 | 2.01 |  |  | SPI(4) MISO | QT1_1 |  | MQS_LEFT |  | 2:1
11 | B0_02 | 2.02 |  |  | SPI(4) MOSI | QT1_2 | 1_TX |  |  | 2:2
13 | B0_03 | 2.03 |  |  | SPI(4) SCK | QT2_0 | 1_RX |  |  | 2:3
6 | B0_10 | 2.10 |  |  |  | PWM2_A2, QT4_1 |  | 1:TX3_RX1 |  | 2:10
9 | B0_11 | 2.11 |  |  |  | PWM2_B2, QT4_2 |  | 1:TX2_RX2 |  | 2:11
32 | B0_12 | 2.12 |  |  |  |  |  | 1:TX1_RX3 | IO-10 | 2:12
8 | B1_00 | 2.16 | Serial2(4) TX |  |  | PWM1_A3 |  | 1:RX_DATA | IO-14 | 2:16, 3:16
7 | B1_01 | 2.17 | Serial2(4) RX |  |  | PWM1_B3 |  | 1:TX_DATA | IO-15 | 2:17, 3:17
37 | SD_B0_00 | 3.12 |  | Wire1(3) SCL | SPI2(1) SCK | PWM1_A0 |  |  | IO-04 |  |  | CMD
36 | SD_B0_01 | 3.13 |  | Wire1(3) SDA | SPI2(1) CS0 | PWM1_B0 |  |  | IO-05 |  |  | CLK
35 | SD_B0_02 | 3.14 | Serial5(8) CTS |  | SPI2(1) MOSI | PWM1_A1 |  |  | IO-06 |  |  | DATA0
34 | SD_B0_03 | 3.15 | Serial5(8) RTS |  | SPI2(1) MISO | PWM1_B1 |  |  | IO-07 |  |  | DATA1
39 | SD_B0_04 | 3.16 | Serial5(8) TX |  | SPI2(1) B_SSO_B | PWM1_A2 |  |  | IO-08 |  |  | DATA2
38 | SD_B0_05 | 3.17 | Serial5(8) RX |  | SPI2(1) B_DQS | PWM1_B2 |  |  | IO-09 |  |  | DATA3
28 | EMC_32 | 3.18 | Serial7(7) RX |  |  | PWM3_B1
31 | EMC_36 | 3.22 |  |  |  | GPT1_2 | 3_TX | 3:TX_DATA | IO-22
30 | EMC_37 | 3.23 |  |  |  | GPT1_3 | 3_RX | 3:MCLK | IO-23
2 | EMC_04 | 4.04 |  |  |  | PWM4_A2 |  | 2:TX_DATA | IO-06 | 1:4
3 | EMC_05 | 4.05 |  |  |  | PWM4_B2 |  | 2:TX_SYNC | IO-07 | 1:5
4 | EMC_06 | 4.06 |  |  |  | PWM2_A0 |  | 2:TX_BCLK | IO-08 | 1:6
33 | EMC_07 | 4.07 |  |  |  | PWM2_B0 |  | 2:MCLK | IO-09 | 1:7
5 | EMC_08 | 4.08 |  |  |  | PWM2_A1 |  | 2:RX_DATA | IO-17 | 1:8
29 | EMC_31 | 4.31 | Serial7(7) TX |  | SPI2(1) CS1 | PWM3_A1

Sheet: T4 card like
Audio | Prop | Native | GPIO | Audio | FlexIO | Xbar | I2C | CAN | SPI | Serial | Analog | PWM | Digital |  |  | Digital | PWM | Analog | Serial | SPI | CAN | I2C | Xbar | FlexIO | Audio | GPIO | Native | Prop | Audio
G | GND |  |  |  |  |  |  |  |  |  | GND |  |  |  |  | Vin |  |  |  |  |  |  |  |  |  |  |  | 5V
 |  | AD_B0_03 | 1.3 |  |  | 17 |  | RX2 | CS1 | RX1 |  | 1X1 | 0 |  |  | GND |  |  |  |  |  |  |  |  |  |  |  | G | G
 |  | AD_B0_02 | 1.2 |  |  | 16 |  | TX2 | MISO1 | TX1 |  | 1X0 | 1 |  |  | 3.3V 250mA max |  |  |  |  |  |  |  |  |  |  |  | 3V | 3.3
 | S | EMC_04 | 4.4 | O2 | 1:4 | 6 |  |  |  |  |  | 4A2 | 2 |  |  | 23 | 4A1 | A9 |  |  | RX1 |  |  | 3:9 | MCL1 | 1.25 | AD-B1_09 |  | A
M |  | EMC_05 | 4.5 | LR2 | 1:5 | 7 |  |  |  |  |  | 4B2 | 3 |  |  | 22 | 4A0 | A8 |  |  | TX1 |  |  | 3:08:00 |  | 1.24 | AD_B1_08
A |  | EMC_06 | 4.6 | BCL2 | 1:6 | 8 |  |  |  |  |  | 2A0 | 4 |  |  | 21 |  | A7 | RX5 |  |  |  |  | 3:11:00 | BCL1 | 1.27 | AD_B1_11 |  | A
A | A-EN | EMC_08 | 4.8 | IN2 | 1:8 | 17 |  |  |  |  |  | 2A1 | 5 |  |  | 20 |  | A6 | TX5 |  |  |  |  | 3:10:00 | LRC1 | 1.26 | AD_B1_10 |  | A
 | M-CS | B0_10 | 2.10 | O1D | 2:10 |  |  |  |  |  |  | 2A2, Q41 | 6 |  |  | 19 | Q30 | A5 | CTS3 |  |  | SCL0 |  | 3:00:00 |  | 1.16 | AD_B1_00 | S | C
 | L-EN | B1_01 | 2.17 | O1A | 2:17, 3:17 | 15 |  |  |  | RX2 |  | 1B3 | 7 |  |  | 18 | Q31 | A4 |  |  |  | SDA0 |  | 3:01:00 |  | 1.17 | AD_B1_01 | S | C
 |  | B1_00 | 2.16 | IN1 | 2:16, 3:16 | 14 | sda0 |  |  | TX2 |  | 1A3 | 8 |  |  | 17 |  | A3 | TX4 |  |  | SDA1 |  | 3:06:00 |  | 1.22 | AD_B1_06
 |  | B0_11 | 2.11 | O1C | 2:11 |  |  |  |  |  |  | 2B2,Q42 | 9 |  |  | 16 |  | A2 | RX4 |  |  | SCL1 |  | 3:07:00 |  | 1.23 | AD_B1_07
S |  | B0_00 | 2.0 | MQR | 2:0 |  |  |  | CS0 |  |  | Q10 | 10 |  |  | 15 | Q33 | A1 | RX3 |  |  |  |  | 3:03:00 | SPDI | 1.19 | AD_B1_03 |  | V
SM | M/L | B0_02 | 2.2 |  | 2:2 |  |  | TX1 | MOSI0 |  |  | Q12 | 11 |  |  | 14 | Q32 | A0 | TX3 |  |  |  |  | 3:02:00 | SPDO | 1.18 | AD_B1_02
SM | M | B0_01 | 2.1 | MQL | 2:1 |  |  |  | MISO0 |  |  | Q11 | 12 |  |  | 13 | Q20 | LED |  | SCK0 | rx1 |  |  | 2:03:00 |  | 2.3 | B0_03 | M | SM
 |  |  |  |  |  |  |  |  |  | Bottom SMT Pins
 |  | AD_B0_12 | 1.12 |  |  |  | SCL2 |  |  | TX6 | A10-1 | 1X2 | 24 |  |  | 25 | 1X3 | A11-1 | RX6 |  |  | SDA2 |  |  |  | 1.13 | AD_B0_13
 |  | AD_B1_14 | 1.30 |  | 3:14 |  |  |  | MOSI1 |  | A12-2 |  | 26 |  |  | 27 |  | A13-2 |  | SCK1 |  |  |  | 3:15 |  | 1.31 | AD_B1_15
 |  | EMC_32 | 3.18 |  |  |  |  |  |  | RX7 |  | 3B1 | 28 |  |  | 29 | 3A1 |  | TX7 |  |  |  |  |  |  | 4.31 | EMC_31
 |  | EMC_37 | 3.23 |  |  | 23 |  | RX3 |  |  |  | G13 | 30 |  |  | 31 | G12 |  |  |  | TX3 |  | 22 |  |  | 3.22 | EMC_36
 |  | B0_12 | 2.12 | O1B | 2:12:00 | 10 |  |  |  |  |  |  | 32 |  |  | 33 | 2B0 |  |  |  | TX1 |  | 9 | 1:7 | MCL2 | 4.7 | EMC_07
 |  |  |  |  |  |  |  |  |  | Bottom SDIO Pins
 |  | SD_B0_03 | 3.15 |  | DATA1 | 7 |  |  | MISO2 |  |  | 1B1 | 34 | ______| | |_____
 |  | SD_B0_02 | 3.14 |  | DATA0 | 6 |  |  | MOSI2 | CTS5 |  | 1A1 | 35 | _______| | |_______
 |  |  |  |  |  |  |  |  |  |  | GND |  |  | _________| | |_______
 |  | SD_B0_01 | 3.13 |  | CLK | 5 | SDA1 |  | CS2 |  |  | 1B0 | 36 | __________| | |___________
 |  |  |  |  |  |  |  |  |  |  | 3.3V 250mA max
 |  | SD_B0_00 | 3.12 |  | CMD | 4 | SCL1 |  | SCK2 |  |  | 1A0 | 37
 |  | SD_B0_05 | 3.17 |  | DATA3 | 9 |  |  |  | RX5 |  | 1B2 | 38
 |  | SD_B0_04 | 3.16 |  | DATA2 | 8 |  |  |  | TX5 |  | 1A2 | 39

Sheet: T4.1 (NM)
Pin | Name | GPIO | Serial | I2C | SPI | PWM | CAN | Audio | XBAR | FlexIO | Analog | SD/CSI/LCD | Special Fea | Column1
0 | AD_B0_03 | 1.3 | Serial1(6) RX |  | SPI1(3) CS0 | PWM1_X1 | 2_RX |  | IO-17
1 | AD_B0_02 | 1.2 | Serial1(6) TX |  | SPI1(3) MISO | PWM1_X0 | 2_TX |  | IO-16
2 | EMC_04 | 4.4 |  |  |  | PWM4_A2 |  | 2:TX_DATA | IO-06 | 1:4
3 | EMC_05 | 4.5 |  |  |  | PWM4_B2 |  | 2:TX_SYNC | IO-07 | 1:5
4 | EMC_06 | 4.6 |  |  |  | PWM2_A0 |  | 2:TX_BCLK | IO-08 | 1:6
5 | EMC_08 | 4.8 |  |  |  | PWM2_A1 |  | 2:RX_DATA | IO-17 | 1:8
6 | B0_10 | 2.10 |  |  |  | PWM2_A2, QT4_1 |  | 1:TX3_RX1 |  | 2:10
7 | B1_01 | 2.17 | Serial2(4) RX |  |  | PWM1_B3 |  | 1:TX_DATA | IO-15 | 2:17, 3:17
8 | B1_00 | 2.16 | Serial2(4) TX |  |  | PWM1_A3 |  | 1:RX_DATA | IO-14 | 2:16, 3:16
9 | B0_11 | 2.11 |  |  |  | PWM2_B2,QT4_2 |  | 1:TX2_RX2 |  | 2:11
10 | B0_00 | 2.0 |  |  | SPI(4) CS0 | QT1_0 |  | MQS_RIGHT |  | 2:0
11 | B0_02 | 2.2 |  |  | SPI(4) MOSI | QT1_2 | 1_TX |  |  | 2:2
12 | B0_01 | 2.1 |  |  | SPI(4) MISO | QT1_1 |  | MQS_LEFT |  | 2:1
13 | B0_03 | 2.3 |  |  | SPI(4) SCK | QT2_0 | 1_RX |  |  | 2:3 |  |  | Internal Led
14/A0 | AD_B1_02 | 1.18 | Serial3(2) TX |  |  | QT3_2 |  | SPDIF_OUT |  | 3:2 | A1:7, A2:7
15/A1 | AD_B1_03 | 1.19 | Serial3(2) RX |  |  | QT3_3 |  | SPDIF_IN |  | 3:3 | A1:8, A2:8
16/A2 | AD_B1_07 | 1.23 | Serial4(3) RX | Wire1(3) SCL |  |  |  | SPDIF_EXTCLK |  | 3:7 | A1:12, A2:12 | CSI_HSYNC
17/A3 | AD_B1_06 | 1.22 | Serial4(3) TX | Wire1(3) SDA |  |  |  | SPDIF_LOCK |  | 3:6 | A1:11, A2:11 | CSI_VSYNC
18/A4 | AD_B1_01 | 1.17 | Serial3(2) RTS | Wire(1) SDA |  | QT3_1 |  |  |  | 3:1 | A1:6, A2:6
19/A5 | AD_B1_00 | 1.16 | Serial3(2) CTS | Wire(1) SCL |  | QT3_0 |  |  |  | 3:0 | A1:5, A2:5
20/A6 | AD_B1_10 | 1.26 | Serial5(8) TX |  |  |  |  | 1:RX_SYNC |  | 3:10 | A1:15, A2:15 | CSI_D7
21/A7 | AD_B1_11 | 1.27 | Serial5(8) RX |  |  |  |  | 1:RX_BCLK |  | 3:11 | A1:0, A2:0 | CSI_D6
22/A8 | AD_B1_08 | 1.24 |  |  |  | PWM4_A0 | 1_TX |  |  | 3:8 | A1:13, A2:13 | CSI_D9
23/A9 | AD_B1_09 | 1.25 |  |  |  | PWM4_A1 | 1_RX | 1:MCLK |  | 3:9 | A1:14, A2:14 | CSI_D8
--- | ---- | ---- | ------ | --- | --- | --- | --- | ---- | ---- | ----- | ------
24/A10 | AD_B0_12 | 1.12 | Serial6(1) TX | Wire2(4) SCL |  | PWM1_X2 |  |  |  |  | A1:1
25/A11 | AD_B0_13 | 1.13 | Serial6(1) RX | Wire2(4) SDA |  | PWM1_X3 | GPT1_CLK |  |  |  | A1:2
26/A12 | AD_B1_14 | 1.30 |  |  | SPI1(3) MOSI |  |  | 1:TX_BCLK |  | 3:14 | A2:3 | CSI_D3
27/A13 | AD_B1_15 | 1.31 |  |  | SPI1(3) SCK |  |  | 1:TX_SYNC |  | 3:15 | A2:4 | CSI_D2
28 | EMC_32 | 3.18 | Serial7(7) RX |  |  | PWM3_B1
29 | EMC_31 | 4.31 | Serial7(7) TX |  | SPI2(1) CS1 | PWM3_A1
30 | EMC_37 | 3.23 |  |  |  | GPT1_3 | 3_RX | 3:MCLK | IO-23
31 | EMC_36 | 3.22 |  |  |  | GPT1_2 | 3_TX | 3:TX_DATA | IO-22
32 | B0_12 | 2.12 |  |  |  |  |  | 1:TX1_RX3 | IO-10 | 2:12
33 | EMC_07 | 4.7 |  |  |  | PWM2_B0 |  | 2:MCLK | IO-09 | 1:7
34 | B1_13 | 2.29 | Serial8(5) RX |  |  |  |  |  |  | 2:29,3:29
35 | B1_12 | 2.28 | Serial8(5) TX |  |  |  |  |  |  | 2:28,3:28
36 | B1_02 | 2.18 |  |  | SPI(4) CS2 | PWM2_A3 |  | 1:TX_BCLK | IO-16 | 2:18,3:18
37 | B1_03 | 2.19 |  |  | SPI(4) CS1 | PWM2_B3 |  | 1:TX_SYNC | IO-17 | 2:19,3:19
38/A14 | AD_B1_12 | 1.28 |  |  | SPI1(3) CS0 |  |  | 1:rx_data |  | 3:12 | A2:1 | CSI_D5
39/A5 | AD_B1_13 | 1.29 |  |  | SPI1(3) MISO |  |  | 1:tx_data |  | 3:13 | A2:2 | CSI_D4
40/A16 | AD_B1_04 | 1.20 |  |  |  |  |  |  |  | 3:4 | A1:9,A2:9 | CSI_PIXCLK
41/A17 | AD_B1_05 | 1.21 |  |  |  | GPT2_1 |  |  |  | 3:5 | A1:10,A2:10 | CSI_MCLK |  | Not Used
SD Pins - Cable connector(T4 34-39)
42 | SD_B0_03 | 3.15 | Serial5(8) RTS |  | SPI2(1) MISO | PWM1_B1 |  |  | IO-07 |  |  | DATA1
43 | SD_B0_02 | 3.14 | Serial5(8) CTS |  | SPI2(1) MOSI | PWM1_A1 |  |  | IO-06 |  |  | DATA0
44 | SD_B0_01 | 3.13 |  | Wire1(3) SDA | SPI2(1) CS0 | PWM1_B0 |  |  | IO-05 |  |  | CLK
45 | SD_B0_00 | 3.12 |  | Wire1(3) SCL | SPI2(1) SCK | PWM1_A0 |  |  | IO-04 |  |  | CMD
46 | SD_B0_05 | 3.17 | Serial5(8) RX |  | FLEXSPI B_DQS | PWM1_B2 |  |  | IO-09 |  |  | DATA3
47 | SD_B0_04 | 3.16 | Serial5(8) TX |  | FLEXSPI B_SSO_B | PWM1_A2 |  |  | IO-08 |  |  | DATA2
Bottom Memory Connectors
48 | EMC_24 | 4:24 | Serial8(5) RX |  | FLEXSPI2_A_SS0_B | PWM1_B0
49 | EMC_27 | 4:27 | Serial8(5) RTS |  | FLEXSPI2_A_DATA01, SPI2(1) SCK | PWM1_A2 |  |  |  | 1:13
50 | EMC_28 | 4:28 | Serial8(5) CTS |  | FLEXSPI2_A_DATA02, SPI2(1) MOSI | PWM1_B2 |  |  |  | 1:14
51 | EMC_22 | 4:22 |  | Wire1(3) SCL | FLEXSPI2_A_SS1_B | PWM3_B3, QT2_3
52 | EMC_26 | 4:26 | Serial1(6) RX |  | FLEXSPI2_A_DATA00 | PWM1_B1 |  |  |  | 1:12
53 | EMC_25 | 4:25 | Serial1(6) TX |  | FLEXSPI2_A_SCLK | PWM1_A1
54 | EMC_29 | 4:29 | Serial1(6) RTS |  | FLEXSPI2_A_DATA03, SPI2(1) MISO | PWM3_A0 |  |  |  | 1:15

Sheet: T4.1 Custom
Pin | Name | GPIO | Serial | I2C | SPI | PWM | CAN | Audio | XBAR | FlexIO | Analog | SD/CSI/LCD | Special Fea | Column1
0 | AD_B0_03 | 1.3 | Serial1(6) RX |  | SPI1(3) CS0 | PWM1_X1 | 2_RX |  | IO-17
1 | AD_B0_02 | 1.2 | Serial1(6) TX |  | SPI1(3) MISO | PWM1_X0 | 2_TX |  | IO-16
2 | EMC_04 | 4.4 |  |  |  | PWM4_A2 |  | 2:TX_DATA | IO-06 | 1:4
3 | EMC_05 | 4.5 |  |  |  | PWM4_B2 |  | 2:TX_SYNC | IO-07 | 1:5
4 | EMC_06 | 4.6 |  |  |  | PWM2_A0 |  | 2:TX_BCLK | IO-08 | 1:6
5 | EMC_08 | 4.8 |  |  |  | PWM2_A1 |  | 2:RX_DATA | IO-17 | 1:8
6 | B0_10 | 2.10 |  |  |  | PWM2_A2, QT4_1 |  | 1:TX3_RX1 |  | 2:10
7 | B1_01 | 2.17 | Serial2(4) RX |  |  | PWM1_B3 |  | 1:TX_DATA | IO-15 | 2:17, 3:17
8 | B1_00 | 2.16 | Serial2(4) TX |  |  | PWM1_A3 |  | 1:RX_DATA | IO-14 | 2:16, 3:16
9 | B0_11 | 2.11 |  |  |  | PWM2_B2,QT4_2 |  | 1:TX2_RX2 |  | 2:11
10 | B0_00 | 2.0 |  |  | SPI(4) CS0 | QT1_0 |  | MQS_RIGHT |  | 2:0
11 | B0_02 | 2.2 |  |  | SPI(4) MOSI | QT1_2 | 1_TX |  |  | 2:2
12 | B0_01 | 2.1 |  |  | SPI(4) MISO | QT1_1 |  | MQS_LEFT |  | 2:1
13 | B0_03 | 2.3 |  |  | SPI(4) SCK | QT2_0 | 1_RX |  |  | 2:3 |  |  | Internal Led
14/A0 | AD_B1_02 | 1.18 | Serial3(2) TX |  |  | QT3_2 |  | SPDIF_OUT |  | 3:2 | A1:7, A2:7
15/A1 | AD_B1_03 | 1.19 | Serial3(2) RX |  |  | QT3_3 |  | SPDIF_IN |  | 3:3 | A1:8, A2:8
16/A2 | AD_B1_07 | 1.23 | Serial4(3) RX | Wire1(3) SCL |  |  |  | SPDIF_EXTCLK |  | 3:7 | A1:12, A2:12 | CSI_HSYNC
17/A3 | AD_B1_06 | 1.22 | Serial4(3) TX | Wire1(3) SDA |  |  |  | SPDIF_LOCK |  | 3:6 | A1:11, A2:11 | CSI_VSYNC
18/A4 | AD_B1_01 | 1.17 | Serial3(2) RTS | Wire(1) SDA |  | QT3_1 |  |  |  | 3:1 | A1:6, A2:6
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

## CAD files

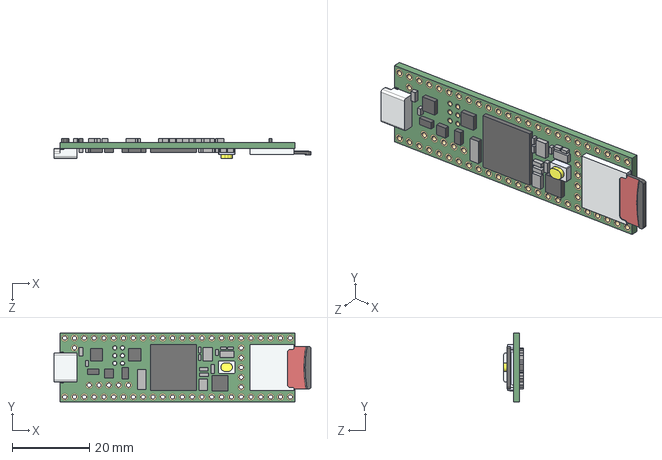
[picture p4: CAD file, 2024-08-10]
CAD Models/Teensy_4.1_Assembly_simplified_colorized/Teensy_4.1_Assembly_simplified.STEP
66.6 x 17.8 x 5.06 mm

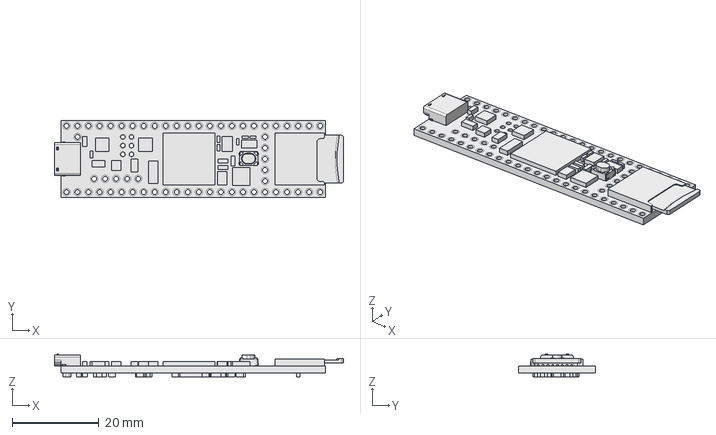
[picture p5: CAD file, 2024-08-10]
CAD Models/Teensy 4.1.FCStd
66.6 x 17.8 x 5.27 mm

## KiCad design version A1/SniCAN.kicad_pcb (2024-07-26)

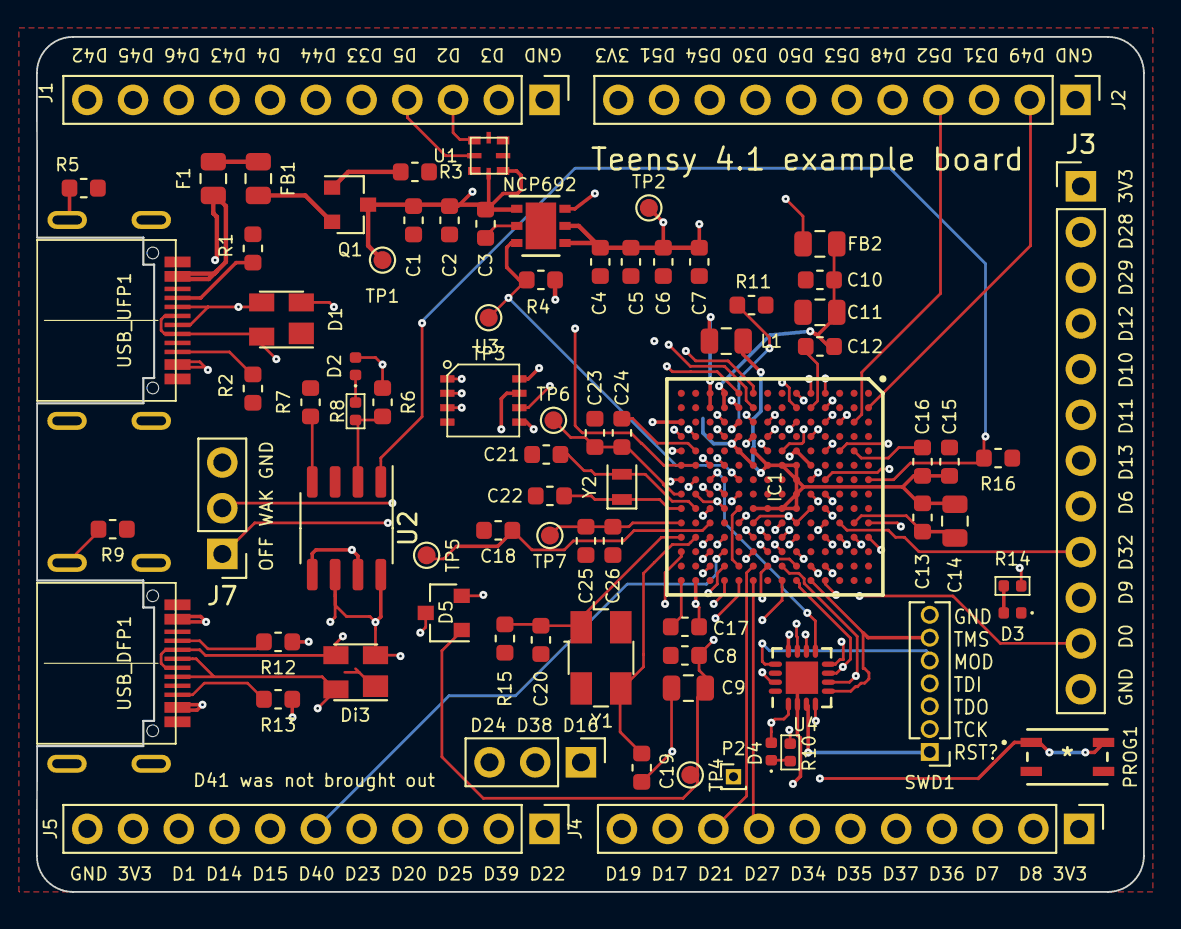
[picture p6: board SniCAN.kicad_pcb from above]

Board: 4 copper layers, 61.5 x 47.5 mm, 80 parts (0 on the bottom side), 109 nets.

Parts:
C1, C2, C4, C8, C10, C13, C17, C18, C23, C25: 0.22uf; C_0603_1608Metric
C3, C7: 2.2uf; C_0603_1608Metric
C5, C16: 10nf; C_0603_1608Metric
C6, C12, C15, C24, C26: 4.7uf; C_0603_1608Metric
C9, C11, C14: 10uf; C_0805_2012Metric
C19, C20: 10pf; C_0603_1608Metric
C21, C22: 9pf; C_0603_1608Metric
D1: SP0503BAHT; SOT-143
D2, D3, D4: LED; LED_0402_1005Metric
D5: BAT54C; SOT-23
Di3: SP0503BAHT; SOT-143
F1: Fuse; R_0805_2012Metric
FB1, FB2: Ferrite_Bead; R_0805_2012Metric
IC1: MIMXRT1062DVJ6B; BGA196C80P14X14_1200X1200X152
J1, J2, J4, J5: Conn_01x11_Male; PinHeader_1x11_P2.54mm_Vertical
J3: Conn_01x12_Male; PinHeader_1x12_P2.54mm_Vertical
J6, J7: Conn_01x03_Male; PinHeader_1x03_P2.54mm_Vertical
L1: 4.7uH; C_0805_2012Metric
NCP692: OnSemi NCP692, fixed version; DFN-6-1EP_3x3mm_P0.95mm_EP1.7x2.6mm
P2: D26; PinHeader_1x01_P1.00mm_Vertical
PROG1: SW_Push; KMR241GLFS
Q1: Q_PMOS_GDS; SOT-23
R1, R2: 5.1k; R_0603_1608Metric
R3, R4, R11, R16: 100k; R_0603_1608Metric
R5, R9: 1M; R_0603_1608Metric
R6, R7: 16k; R_0603_1608Metric
R8, R10, R14: 1k; R_0402_1005Metric
R12, R13: 56k; R_0603_1608Metric
R15: 2.2M; R_0603_1608Metric
SWD1: SWD; PinHeader_1x07_P1.27mm_Vertical
TP1, TP2, TP3, TP4, TP5, TP6, TP7: TestPoint; TestPoint_Pad_D1.0mm
U1: opto_APA102-2020; APA102-2020
U2: MAX1562; SO-8_3.9x4.9mm_P1.27mm
U3: W25Q64JVXGIM; XSON8_4x4mm
U4: MKL02Z32VFG4; QFN-16-1EP_3x3mm_P0.5mm_EP1.8x1.8mm
USB_DFP1: USB_C_Receptacle_USB2.0; TYPE-C-31-M-14
USB_UFP1: USB_C_Receptacle_USB2.0; TYPE-C-31-M-14
Y1: Crystal_GND23; Crystal_SMD_Abracon_ABM3B-4Pin_5.0x3.2mm
Y2: Crystal; Crystal_SMD_2012-2Pin_2.0x1.2mm

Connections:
+3V3: C4.1, C5.1, C6.1, C7.1, C17.1, D4.2 (A), D5.2, FB2.2, IC1.E6 (NVCC_EMC_1), IC1.E9 (NVCC_GPIO_1), IC1.F5 (NVCC_EMC_2), IC1.F10 (NVCC_GPIO_2), IC1.J6 (NVCC_SD0), IC1.J10 (NVCC_GPIO_3), IC1.K4 (DCDC__IN_Q), IC1.K5 (NVCC_SD1), IC1.N14 (VDDA_ADC_3P3), IC1.P12 (VDD_HIGH_IN), J2.11, J3.1, J4.1, J5.10, NCP692.4 (OUT), NCP692.5 (SNS), R4.2, TP2.1, U3.8 (VDD), U4.1 (VDD/VREFH)
+5V: C1.1, C2.1, C3.1, IC1.N6 (USB_OTG1_VBUS), IC1.P6 (USB_OTG2_VBUS), NCP692.1 (IN), NCP692.6 (IN), Q1.3 (S), TP1.1, U1.1 (VDD)
+5VD: D1.2 (K), D2.2 (A), F1.1, R6.1, U2.5 (IN), U2.7 (IN), USB_UFP1.A4 (VBUS), USB_UFP1.A9 (VBUS), USB_UFP1.B4 (VBUS), USB_UFP1.B9 (VBUS)
+5VL: Di3.2 (K), R12.1, R13.1, U2.6 (OUT), U2.8 (OUT), USB_DFP1.A4 (POW), USB_DFP1.A9 (POW), USB_DFP1.B4 (POW), USB_DFP1.B9 (POW)
/D0: IC1.G11 (GPIO_AD_B0_03), J3.11
/D1: IC1.M11 (GPIO_AD_B0_02), J5.9
/D2: IC1.F2 (GPIO_EMC_04), J1.3, U1.4 (SDI)
/D3: IC1.G5 (GPIO_EMC_05), J1.2
/D4: IC1.H5 (GPIO_EMC_06), J1.7
/D5: IC1.H3 (GPIO_EMC_08), J1.4, U1.5 (CKI)
/D6: IC1.D9 (GPIO_B0_10), J3.8
/D7: IC1.B11 (GPIO_B1_01), J4.3
/D8: IC1.A11 (GPIO_B1_00), J4.2
/D9: IC1.A10 (GPIO_B0_11), J3.10
/D10: IC1.D7 (GPIO_B0_00), J3.5
/D11: IC1.E8 (GPIO_B0_02), J3.6
/D12: IC1.E7 (GPIO_B0_01), J3.4
/D13: IC1.D8 (GPIO_B0_03), J3.7, R14.1
/D14_A0: IC1.L11 (GPIO_AD_B1_02), J5.8
/D15_A1: IC1.M12 (GPIO_AD_B1_03), J5.7
/D16_A2: IC1.K10 (GPIO_AD_B1_07), J6.1
/D17_A3: IC1.J12 (GPIO_AD_B1_06), J4.10
/D19_A5: IC1.J11 (GPIO_AD_B1_00), J4.11
/D20_A6: IC1.L13 (GPIO_AD_B1_10), J5.4
/D21_A7: IC1.J13 (GPIO_AD_B1_11), J4.9
/D22_A8: IC1.H13 (GPIO_AD_B1_08), J5.1
/D23_A9: IC1.M13 (GPIO_AD_B1_09), J5.5
/D24_A10: IC1.K14 (GPIO_AD_B0_12), J6.3
/D25_A11: IC1.L14 (GPIO_AD_B0_13), J5.3
/D26_A12: IC1.G12 (GPIO_AD_B1_14), P2.1
/D27_A13: IC1.J14 (GPIO_AD_B1_15), J4.8
/D28: IC1.D5 (GPIO_EMC_32), J3.2
/D29: IC1.C5 (GPIO_EMC_31), J3.3
/D30: IC1.E4 (GPIO_EMC_37), J2.8
/D31: IC1.C3 (GPIO_EMC_36), J2.3
/D32: IC1.C10 (GPIO_B0_12), J3.9
/D33: IC1.H4 (GPIO_EMC_07), J1.5
/D34: IC1.D14 (GPIO_B1_13), J4.7
/D35: IC1.D13 (GPIO_B1_12), J4.6
/D36: IC1.C11 (GPIO_B1_02), J4.4
/D37: IC1.D11 (GPIO_B1_03), J4.5
/D38_A14: IC1.H12 (GPIO_AD_B1_12), J6.2
/D39_A15: IC1.H11 (GPIO_AD_B1_13), J5.2
/D40_A16: IC1.L12 (GPIO_AD_B1_04), J5.6
/D42: IC1.K1 (GPIO_SD_B0_03), J1.11
/D43: IC1.J1 (GPIO_SD_B0_02), J1.8
/D44: IC1.J3 (GPIO_SD_B0_01), J1.6
/D45: IC1.J4 (GPIO_SD_B0_00), J1.10
/D46: IC1.J2 (GPIO_SD_B0_05), J1.9
/D48: IC1.D3 (GPIO_EMC_24), J2.5
/D49: IC1.A2 (GPIO_EMC_27), J2.2
/D50: IC1.D1 (GPIO_EMC_28), J2.7
/D51: IC1.F1 (GPIO_EMC_22), J2.10
/D52: IC1.B3 (GPIO_EMC_26), J2.4
/D53: IC1.D2 (GPIO_EMC_25), J2.6
/D54: IC1.E1 (GPIO_EMC_29), J2.9
/DCDC_PSWITCH: IC1.G10 (GPIO_AD_B0_11), IC1.K3 (DCDC_PSWITCH), R11.2, SWD1.1, U4.3 (PTA3)
/JTAG_MOD: IC1.F13 (GPIO_AD_B0_08), SWD1.5, U4.13 (PTB5/IRQ_12)
/JTAG_TCK: IC1.F12 (GPIO_AD_B0_07), SWD1.2, U4.8 (PTB0/IRQ_5)
/JTAG_TDI: IC1.F14 (GPIO_AD_B0_09), SWD1.4, U4.7 (PTA7/IRQ_4)
/JTAG_TDO: IC1.G13 (GPIO_AD_B0_10), SWD1.3, U4.6 (PTA6)
/JTAG_TMS: IC1.E14 (GPIO_AD_B0_06), SWD1.6, U4.5 (PTA5)
/ONOFF: IC1.M6 (ONOFF), J7.1
/PMIC_ON_REQ_PWR_SEQ: IC1.K7 (PMIC_ON_REQ), NCP692.3 (EN), R4.1, TP3.1
/POR_B: IC1.M7 (POR_B), U4.9 (PTB1/IRQ_6)
/SOC_CAP_NET: C13.1, C14.1, C15.1, C16.1, IC1.F6 (VDD_SOC_IN_1), IC1.F7 (VDD_SOC_IN_2), IC1.F8 (VDD_SOC_IN_3), IC1.F9 (VDD_SOC_IN_4), IC1.G6 (VDD_SOC_IN_5), IC1.G9 (VDD_SOC_IN_6), IC1.H6 (VDD_SOC_IN_7), IC1.H9 (VDD_SOC_IN_8), IC1.J5 (DCDC_SENSE), IC1.J9 (VDD_SOC_IN_9), L1.2
/USB1_DN: D1.3 (K), IC1.M8 (USB_OTG1_DN), USB_UFP1.A7 (D-), USB_UFP1.B7 (D-)
/USB1_DP: D1.4 (K), IC1.L8 (USB_OTG1_DP), USB_UFP1.A6 (D+), USB_UFP1.B6 (D+)
/USB2_DN: Di3.3 (K), IC1.N7 (USB_OTG2_DN), USB_DFP1.A7 (D-), USB_DFP1.B7 (D-)
/USB2_DP: Di3.4 (K), IC1.P7 (USB_OTG2_DP), USB_DFP1.A6 (D+), USB_DFP1.B6 (D+)
/WAKEUP: IC1.L6 (WAKEUP), J7.2
GND: C1.2, C2.2, C3.2, C4.2, C5.2, C6.2, C7.2, C8.2, C9.2, C10.2, C11.2, C12.2, C13.2, C14.2, C15.2, C16.2, C17.2, C18.2, C19.2, C20.2, C21.2, C22.2, C23.2, C24.2, C25.2, C26.2, D1.1 (A), D3.1 (K), Di3.1 (A), IC1.A1 (VSS_1), IC1.A14 (VSS_2), IC1.B5 (VSS_3), IC1.B10 (VSS_4), IC1.E2 (VSS_5), IC1.E13 (VSS_6), IC1.G7 (VSS_7), IC1.G8 (VSS_8), IC1.G14 (GPIO_AD_B0_05), IC1.H7 (VSS_9), IC1.H8 (VSS_10), IC1.J7 (VSS_11), IC1.J8 (VSS_12), IC1.K2 (VSS_13), IC1.K9 (NGND_KEL0), IC1.K13 (VSS_14), IC1.L9 (VSS_15), IC1.N1 (DCDC_GND_1), IC1.N2 (DCDC_GND_2), IC1.N5 (VSS_16), IC1.N8 (VSS_17), IC1.P1 (VSS_18), IC1.P14 (VSS_19), J1.1, J2.1, J3.12, J5.11, J7.3, NCP692.2 (GND), NCP692.7 (GND), PROG1.2, R1.1, R2.1, R3.1, R5.1, R7.1, R9.1, R11.1, R15.1, R16.1, SWD1.7, U1.6 (GND), U2.3 (GND), U3.4 (GND), U4.2 (VSS/VREFL), U4.17 (EPAD), USB_DFP1.A1 (GND), USB_DFP1.A12 (GND), USB_DFP1.B1 (GND), USB_DFP1.B12 (GND), USB_UFP1.A1 (GND), USB_UFP1.A12 (GND), USB_UFP1.B1 (GND), USB_UFP1.B12 (GND), Y1.2, Y1.4
unnamed: C8.1, C9.1, D5.1, IC1.K8 (VDD_USB_CAP), TP4.1
unnamed: C10.1, C11.1, C12.1, FB2.1, IC1.L1 (DCDC_IN_1), IC1.L2 (DCDC_IN_2)
unnamed: C18.1, IC1.M10 (VDD_SNVS_CAP), TP5.1
unnamed: C19.1, IC1.N11 (XTALO), Y1.3
unnamed: C20.1, IC1.P11 (XTALI), R15.2, Y1.1
unnamed: C21.1, IC1.N9 (RTC_XTALI), Y2.2
unnamed: C22.1, IC1.P9 (RTC_XTALO), Y2.1
unnamed: C23.1, C24.1, IC1.P8 (VDD_HIGH_CAP), TP6.1
unnamed: C25.1, C26.1, IC1.P10 (NVCC_PLL), TP7.1
unnamed: D2.1 (K), R8.1
unnamed: D3.2 (A), R14.2
unnamed: D4.1 (K), R10.2
unnamed: D5.3, IC1.M9 (VDD_SNVS_IN)
unnamed: F1.2, FB1.1
unnamed: FB1.2, Q1.2 (D)
unnamed: IC1.A7 (GPIO_EMC_40), R16.2, U2.1 (ON)
unnamed: IC1.D10 (GPIO_B0_13), U4.12 (PTB4/IRQ_11)
unnamed: IC1.F3 (GPIO_EMC_01), U4.15 (PTA1/IRQ_1/LPTMR0_ALT1)
unnamed: IC1.F11 (GPIO_AD_B0_04), U4.4 (PTA4)
unnamed: IC1.L3 (GPIO_SD_B1_06), U3.1 (CS)
unnamed: IC1.L4 (GPIO_SD_B1_07), U3.6 (CLK)
unnamed: IC1.M1 (DCDC_LP_1), IC1.M2 (DCDC_LP_2), L1.1
unnamed: IC1.N4 (GPIO_SD_B1_09), U3.2 (D1)
unnamed: IC1.P3 (GPIO_SD_B1_08), U3.5 (D0)
unnamed: IC1.P4 (GPIO_SD_B1_10), U3.3 (D2)
unnamed: IC1.P5 (GPIO_SD_B1_11), U3.7 (D3)
unnamed: PROG1.1, U4.10 (PTB2/IRQ_7)
unnamed: Q1.1 (G), R3.2
unnamed: R1.2, USB_UFP1.A5 (CC1)
unnamed: R2.2, USB_UFP1.B5 (CC2)
unnamed: R5.2, USB_UFP1.S1 (SHIELD)
unnamed: R6.2, R8.2, U2.2 (Fault)
unnamed: R7.2, U2.4 (ISET)
unnamed: R9.2, USB_DFP1.S1 (SHIELD)
unnamed: R10.1, U4.11 (PTB3/IRQ_10)
unnamed: R12.2, USB_DFP1.A5 (CC1)
unnamed: R13.2, USB_DFP1.B5 (CC2)

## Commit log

2024-07-26 initial commit
    first commit with all the initial files for HW project
    [SniCAN.kicad_pcb, SniCAN.kicad_sch, Sniffer Pinout.xlsx]
2024-08-10 mechanical files added and changes to documents structure
    [Sniffer Pinout.xlsx, Teensy 4.1.FCStd, Teensy K66 Beta Pinout.xlsx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]
2024-08-16 colored pinout
    [SniCAN.kicad_sch, Teensy K66 Beta Pinout.xlsx, Teensy4x Pins.xlsx]

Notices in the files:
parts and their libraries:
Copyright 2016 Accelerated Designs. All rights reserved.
